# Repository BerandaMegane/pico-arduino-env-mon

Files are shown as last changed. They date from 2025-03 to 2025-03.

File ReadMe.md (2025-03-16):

# pico-arduino-env-mon

秋月電子通商で買える部品だけで作れる環境モニタです。

温度、湿度、気圧、CO2濃度を定期的に取得し、24時間のトレンドグラフとともに表示します。

こちらの環境モニタ (MIT license) を参考に製作しました。
* [shapoco / pico-env-mon](https://github.com/shapoco/pico-env-mon)
  * ReadMe.md を一部流用させていただきました。 
  * グラフ描画処理を参考にさせていただきました。

## 作例

3Dプリンタで作ったケースに収めた例です。

基板の作例は [こちらの img ディレクトリ](img/) を参照してください。

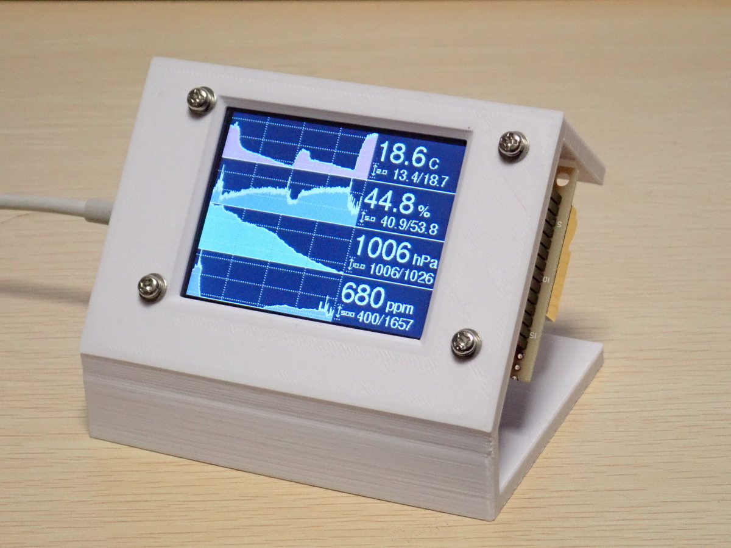
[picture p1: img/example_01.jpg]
作例


## 使用部品

<table>
  <tr>
    <th>項目</th>
    <th>型番・仕様</th>
    <th>購入先 (例)</th>
    <th>備考</th>
  </tr>
  <tr>
    <td rowspan="2">マイコン (どちらか)</td>
    <td>秋月 AE-RP2040</td>
    <td>
      秋月: <a href="https://akizukidenshi.com/catalog/g/g117542/" target="_blank">117542</a>
    </td>
    <td rowspan="2">AE-RP2040で動作確認済み</td>
  </tr>
  <tr>
    <td>Raspberry Pi Pico</td>
    <td>
      秋月: <a href="https://akizukidenshi.com/catalog/g/g116132/" target="_blank">116132</a>
    </td>
  </tr>
  <tr>
    <td>LCD</td>
    <td>MSP2807</td>
    <td>
      秋月: <a href="https://akizukidenshi.com/catalog/g/g116265/" target="_blank">116265</a>
    </td>
    <td>ILI9341 搭載 LCD</td>
  </tr>
  <tr>
    <td>温湿度・気圧センサ</td>
    <td>AE-BME280</td>
    <td>
      秋月: <a href="https://akizukidenshi.com/catalog/g/g109421/" target="blank">109421</a>
    </td>
    <td></td>
  </tr>
  <tr>
    <td>CO2 センサ</td>
    <td>MH-Z19C</td>
    <td>
      秋月: <a href="https://akizukidenshi.com/catalog/g/g116142/" target="blank">116142</a>
    </td>
    <td>*1</td>
  </tr>
  <tr>
    <td>ゼロ点補正スイッチ</td>
    <td>適当なタクトスイッチ</td>
    <td>
      秋月: <a href="https://akizukidenshi.com/catalog/c/cpushsw/" target="blank">検索</a>
      (例: <a href="https://akizukidenshi.com/catalog/g/g103647/" target="blank">103647</a>)
    </td>
    <td></td>
  </tr>
  <tr>
    <td>部品固定用<br>ピンヘッダ</td>
    <td>PH-1x40SG</td>
    <td>
      秋月: <a href="https://akizukidenshi.com/catalog/g/g100167/" target="blank">100167</a>
    </td>
    <td></td>
  </tr>
  <tr>
    <td>部品固定用<br>ピンソケット</td>
    <td>FHU-1x42SG</td>
    <td>
      秋月: <a href="https://akizukidenshi.com/catalog/g/g105779/" target="blank">105779</a>
    </td>
    <td></td>
  </tr>
  <tr>
    <td>ユニバーサル基板</td>
    <td>秋月 Bタイプ 2.54mm</td>
    <td>
      秋月: <a href="https://akizukidenshi.com/catalog/goods/search.aspx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" target="blank">検索</a>
      (例: <a href="https://akizukidenshi.com/catalog/g/g103230/" target="blank">103230</a>)
    </td>
    <td>両面の方が配線しやすい<br>*2</td>
  </tr>
  <tr>
    <td>配線類</td>
    <td>UEW など</td>
    <td>
      秋月: <a href="https://akizukidenshi.com/catalog/c/cwire/" target="blank">検索</a>
      (例: <a href="https://akizukidenshi.com/catalog/g/g109583/" target="blank">109583</a>)
    </td>
    <td></td>
  </tr>
  <tr>
    <td>USB電源</td>
    <td>5V</td>
    <td>
      秋月: <a href="https://akizukidenshi.com/catalog/g/g113658/" target="_blank">113658</a>
    </td>
    <td></td>
  </tr>
  <tr>
    <td>USBケーブル</td>
    <td>Type-C: AE-RP2040, Pi Pico2<br>micro B: Pi Pico</td>
    <td>
      秋月: (例: Type-C <a href="https://akizukidenshi.com/catalog/g/g113563/" target="_blank">113563</a>)
    </td>
    <td>マイコンに適合するもの</td>
  </tr>
</table>

\*1) :warning: MH-Z19C には購入時点でピンヘッダが付いていてそれ自体は 2.54mm ピッチですが、2 つのヘッダの間隔が 2.54mm ピッチのユニバーサル基板に適合しません。  
直接ハンダづけしたい場合は、1.27mm ピッチのユニバーサル基板を使用するか、ピンヘッダを外してスズメッキ線等で配線してください。  
作例ではピンソケットを用いて若干「ハの字」になるように接続しています。

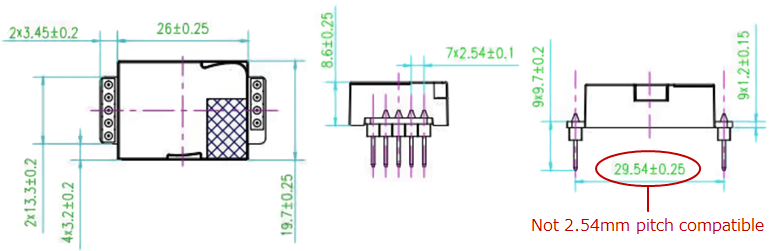
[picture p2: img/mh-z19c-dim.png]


\*2) :warning: ケース用の STL データを使用する場合は適切な大きさにカットする必要があります (後述)。

----

## 接続

|AE-RP2040<br>Raspberry Pi Pico|MSP2807|BME280|MH-Z19C|
|:--|:--|:--|:--|
|`5V`(AE-RP2040)<br>`VBUS`(Pi Pico)|`VCC`||`Vin`|
|`3V3`<br>(AE-RP2040, Pi Pico)||`VDD`||
|`GND`|`GND`|`GND`|`GND`|
|`GPIO0` (uart0 TX)|||`RX`|
|`GPIO1` (uart1 RX)|||`TX`|
|`GPIO16` (spi0 RX)||`SDO`|
|`GPIO17` (spi0 CSn)||`CSB`|
|`GPIO18` (spi0 SCK)|`SCK`|`SCK`|
|`GPIO19` (spi0 TX)|`SDI`|`SDI`|
|`GPIO20`|`DC`||
|`GPIO21`|`RST`||
|`GPIO22`|`CS`||

### AE-RP2040 使用時
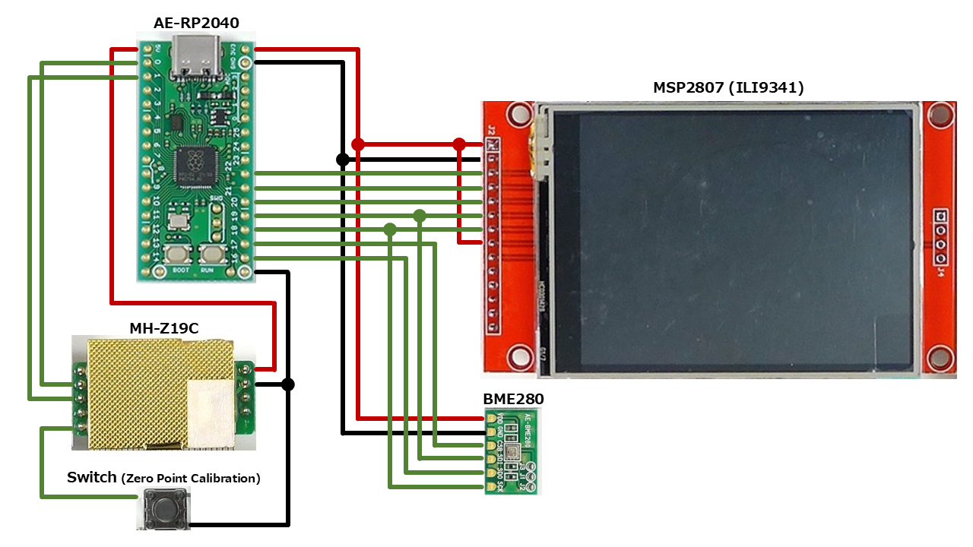
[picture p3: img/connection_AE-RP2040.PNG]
AE-RP2040使用時の接続図


### Raspberry Pi Pico 使用時（未確認）
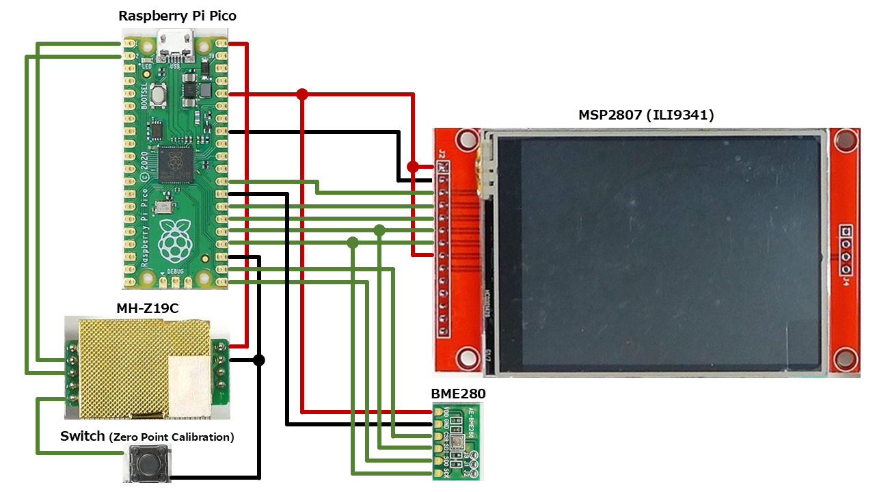
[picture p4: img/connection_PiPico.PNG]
Raspberry Pi Pico使用時の接続図


## 配線・組み立てについて

### 注意事項

:warning: CO2センサー MH-Z19C は内蔵された電球の駆動のために定期的に大きな電流を吸い込みます。これが LCD の動作に悪影響を与えないよう、配線の引き回しやコンデンサの配置に注意する必要があります。

- LCD の表示に問題が生じた場合は:
  - MH-Z19C と LCD それぞれの直近にセラミックコンデンサを実装してみてください。
  - MH-Z19C の直近に電解コンデンサ 47uF を追加してみてください。

### ケースについて

[ケース用の STL のサンプル](case/body.stl) を公開しています。
2.54mm ピッチのユニバーサル基板を 33穴 ✕ 18穴 にカットし、以下のようにレイアウトする前提の形状になっています。

また、STL の元になった [モデルサンプル](case/pico-arduino-env-mon_case.f3d) を公開しています。
Fusion 360 (趣味での利用は無償) で編集することができます。

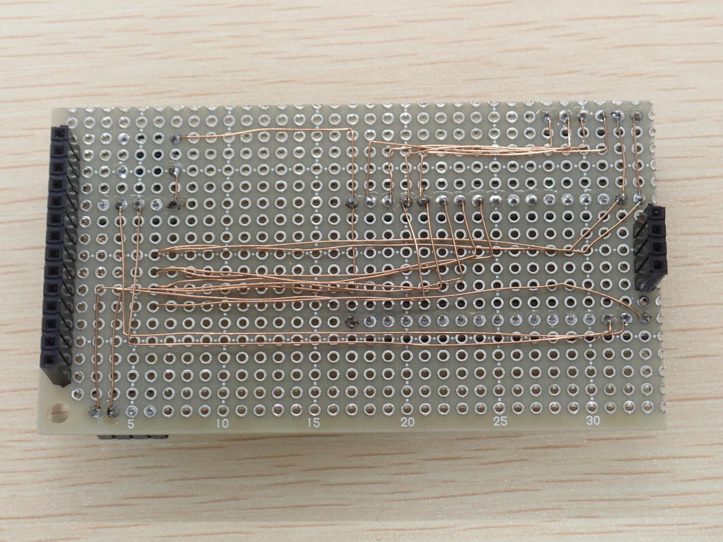
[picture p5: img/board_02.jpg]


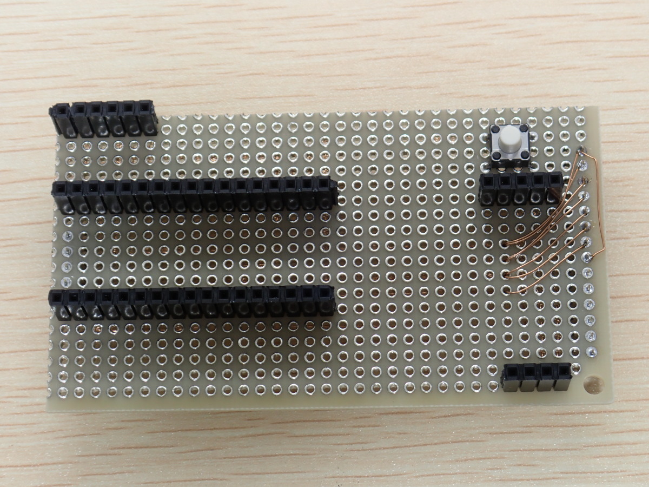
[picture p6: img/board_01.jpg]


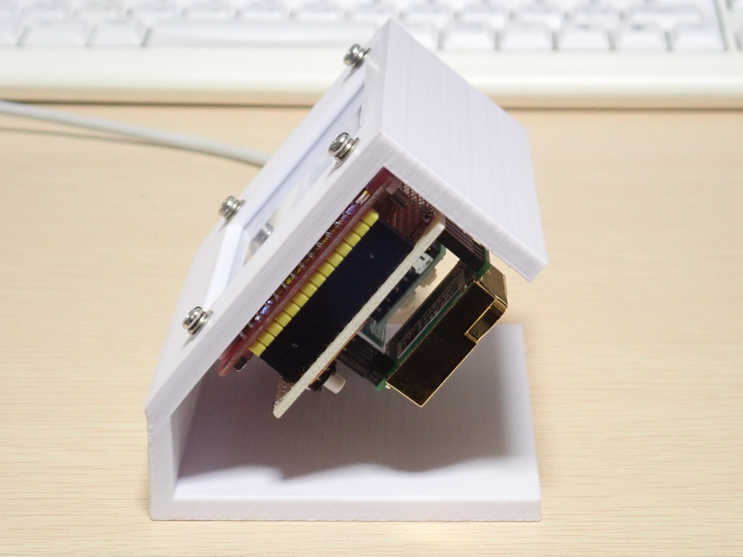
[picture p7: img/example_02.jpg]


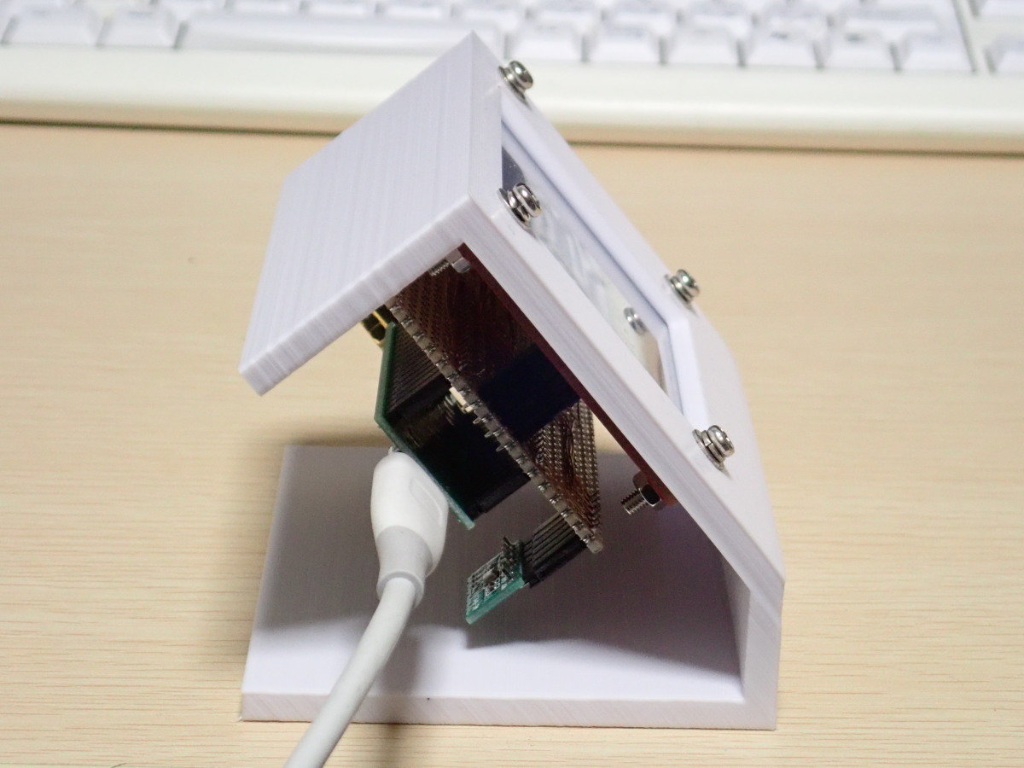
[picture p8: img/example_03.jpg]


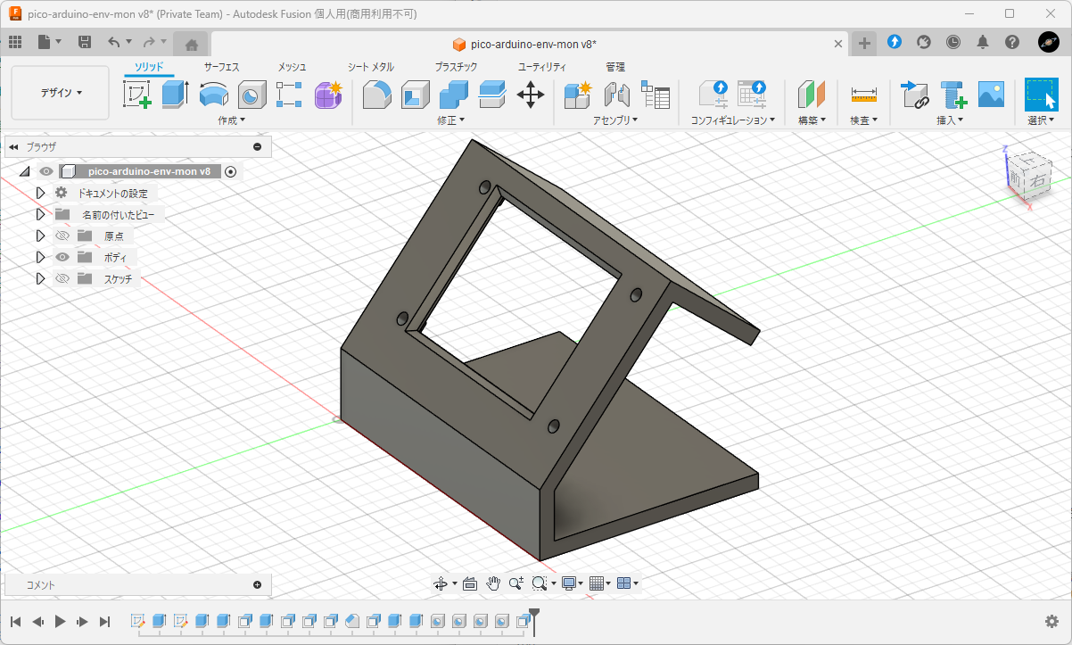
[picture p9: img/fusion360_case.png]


## プログラム

コンパイル済みバイナリをダウンロードしてそのまま書き込むか、またはソースコードからビルドしてください。

### コンパイル済みバイナリ

1. [Releases](https://github.com/BerandaMegane/pico-arduino-env-mon/releases) から、最新バージョンの `pico_arduino_env_mon.uf2` をダウンロードします。
2. マイコンを書き込みモードで PC へ接続します。(USBストレージとして認識されます)  
    書き込みモードへの切り替え方法は使用マイコンによって異なります。
    * Raspberry Pi Pico の場合: `BOOT SEL` ボタンを押しながら USBケーブルを接続します。
    * AE-RP2040 の場合: USBケーブルを接続後、`BOOT` ボタンを押しながら、隣の `RUN` ボタンを押します。
3. `pico-arduino-env-mon.uf2` をマイコンへ書き込みます。

### ソースコードからのビルド

ビルドするには Arduino IDE 2 と Raspberry Pi Pico (RP2040) 開発環境の設定が必要です。  
開発環境の構築方法は次のサイトを参考にしてください。

参考サイト: ロジカラブログ - [ラズパイPico/Pico2/PicoWのArduinoIDE2のインストール方法や使い方紹介](https://logikara.blog/raspi-pico-arduinoide/)

1. 本リポジトリをダウンロードする。

    1. 本ページ上部の `<> Code` をクリック
    2. `Download ZIP` をクリックして任意の場所に展開

2. `pico-arduino-env-mon.ino` を Arduino IDE 2.0 で開く。
3. 必要なライブラリパッケージをインストールする。

    * "Adafruit GFX Library"
    * "Adafruit ILI9341"
    * "Bme280" (by Eduard Malokhvii)

4. マイコンボードの接続設定などを行う。
5. コンパイル＆実行し、ビルドファイルをマイコンへ書き込む。

## 調整

### BME280 の温度

BME280 で取得できる温度の値は湿度と気圧の補正のためのもので、実際の気温より若干高くなります。

> The integrated temperature sensor has been optimized for lowest noise and highest resolution. Its output is used for temperature compensation of the pressure and humidity sensors and can also be used for estimation of the ambient temperature. 

> Temperature measured by the internal temperature sensor. This temperature value depends on the PCB temperature, sensor element self-heating and ambient temperature and is typically above ambient temperature.

実際の気温とどの程度乖離するかはセンサの使用条件によります。ケースに入れたり、BME280 を CO2センサに近接させたりすると乖離が大きくなります。本プロジェクトではこれらを考慮し、デフォルトでは取得した温度から 1.5℃ 減算した値を表示します。

補正値を変更するには、`src/pico-arduino-env-mon.ino` の次の箇所を変更してビルドし直してください。

```c++
const float TEMPERATURE_OFFSET = -2.0;
```

### MH-Z19C のキャリブレーション

MH-Z19C は初期状態では正しい値を示さないケースがあります。

屋外に放置して値が 400ppm 付近まで下がらない場合や、人がいる室内なのに 400ppm 付近に張り付いてしまう場合はキャリブレーションを実施してください。

参考: [Home Assistant: ESP32+MH-Z19CでCO2モニター構築(2) [キャリブレーション編] - Sympapaのスマートホーム日記](https://sympapa.hatenablog.com/entry/2022/06/05/091621)

1. 本機を屋外や誰もいない風通しの良い場所に 20分間放置します。
2. 吐息がかからないように息を止めて、ゼロ点補正 (Zero Point Calibration) スイッチを 7秒間押下します。

なお、本プロジェクトではオートキャリブレーションは無効化されています。

### 時間軸のスケール変更

デフォルトでは 24時間分のグラフが表示されます。

スケールを変更するには、`src/pico-arduino-env-mon.ino` の次の箇所を変更してビルドし直してください。

```c++
const int16_t GRAPH_TIME_RANGE_H = 24;
```

## Lisence

This project is licensed under the MIT License, see the LICENSE.txt file for details

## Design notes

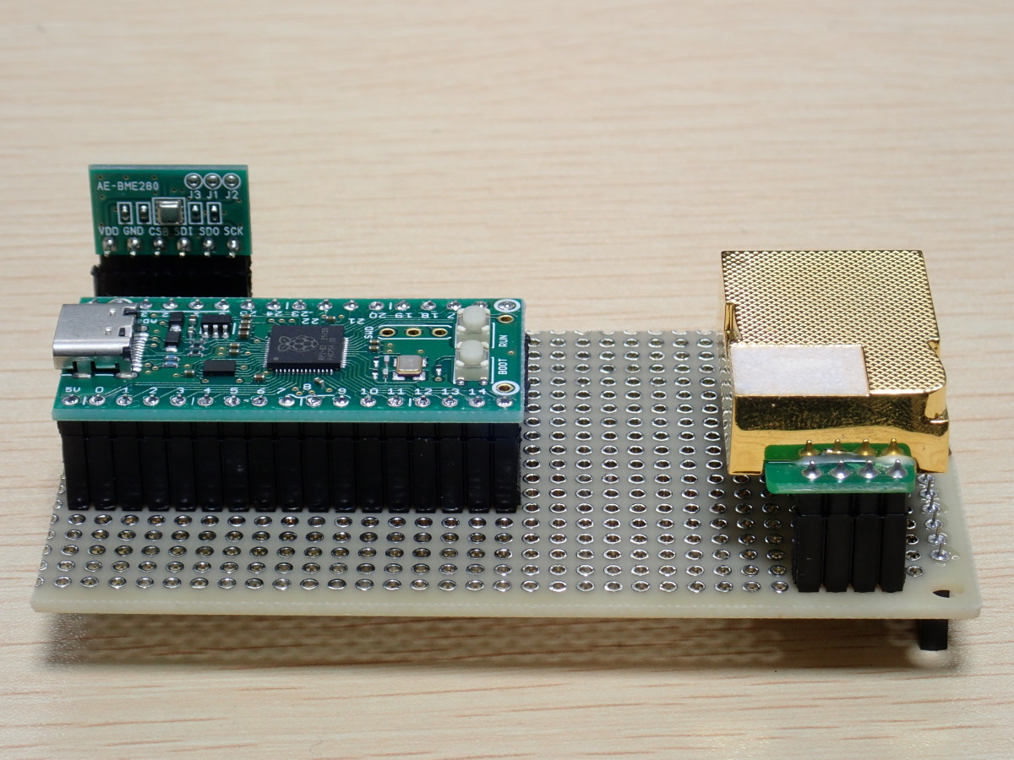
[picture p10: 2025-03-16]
img/board_03.jpg

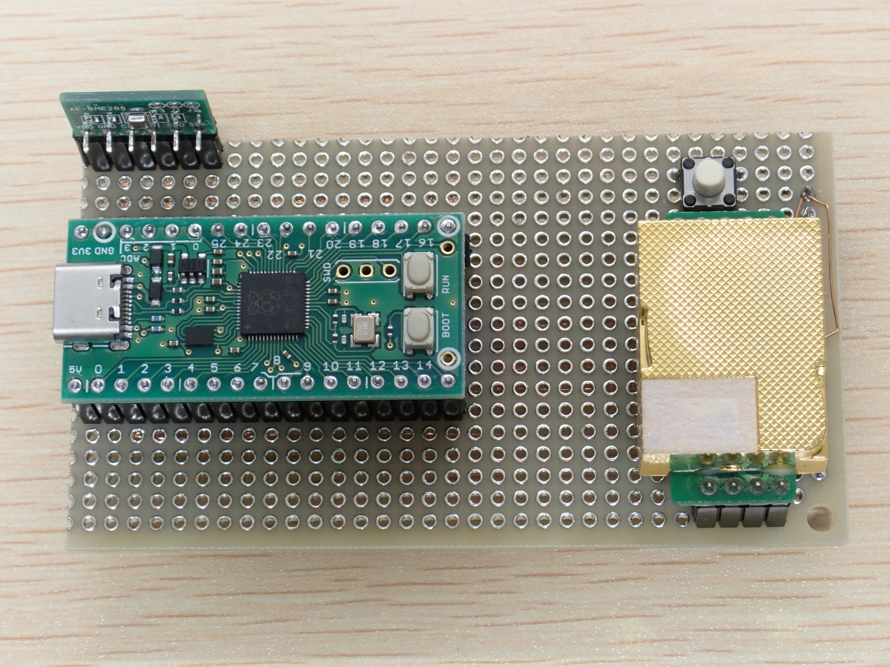
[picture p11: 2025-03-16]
img/board_04.jpg

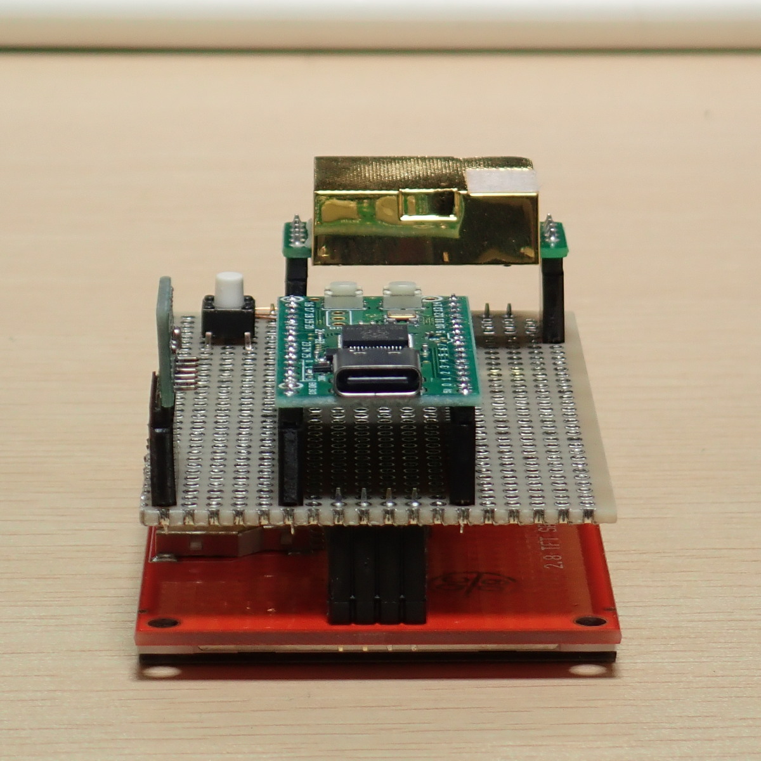
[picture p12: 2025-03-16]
img/board_06.jpg

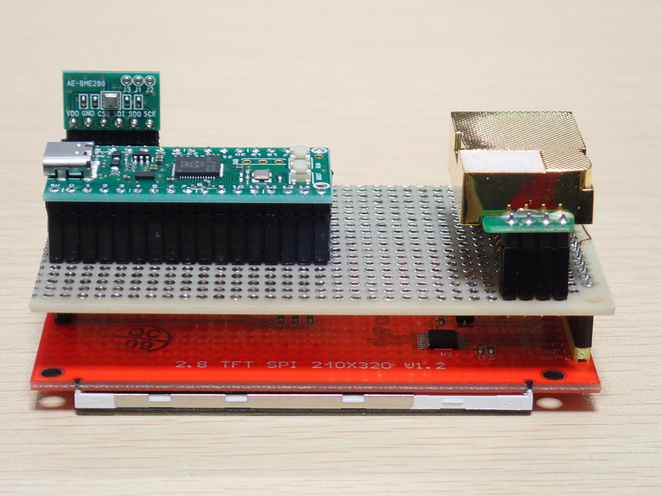
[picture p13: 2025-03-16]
img/board_05.jpg

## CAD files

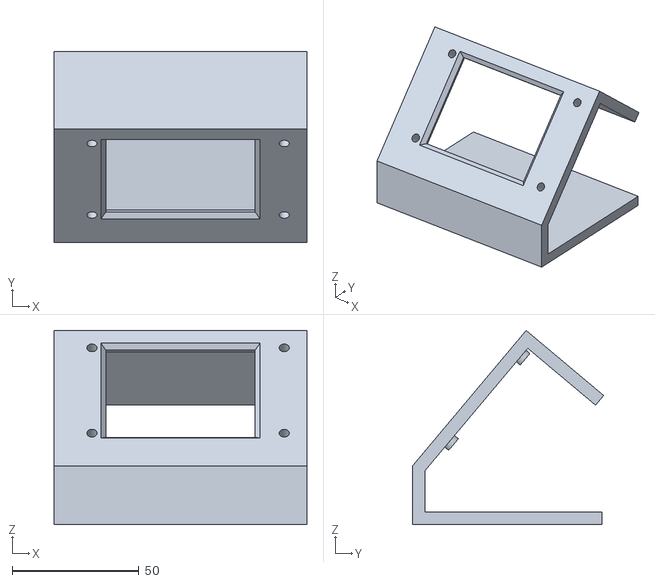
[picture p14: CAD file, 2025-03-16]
case/body.stl
100.0 x 75.6 x 76.7

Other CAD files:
case/pico-arduino-env-mon_case.f3d

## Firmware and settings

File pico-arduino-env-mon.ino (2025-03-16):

/*
Copyright (c) 2022 shapoco
Copyright (c) 2025 BerandaMegane
Released under the MIT license
https://opensource.org/licenses/mit-license.php

shapoco 氏の環境モニタ pico-env-mon を参考に製作しました。
- ReadMe.md を一部流用させていただきました。 
- グラフ描画処理を参考にさせていただきました。
- https://github.com/shapoco/pico-env-mon
*/

// 必要な外部ライブラリ
// https://github.com/adafruit/Adafruit-GFX-Library
#include <Adafruit_GFX.h>  // install "Adafruit GFX Library"
// https://github.com/adafruit/Adafruit_ILI9341
#include <Adafruit_ILI9341.h>  // install "Adafruit ILI9341"
// https://github.com/malokhvii-eduard/arduino-bme280
#include <Bme280.h>  // install "Bme280" (by Eduard Malokhvii)

// フォント
#include <Fonts/FreeSans9pt7b.h>
#include <Fonts/FreeSans18pt7b.h>
#include <Fonts/Org_01.h>

// ピン接続
#define UART_TX    0  // UART TX   (MH-Z19C RX)
#define UART_RX    1  // UART RX   (MH-Z19C TX)
#define SPI_MISO  16  // SPI0 MISO (BME280, ILI9341)
#define BME280_CS 17  // SPI  CS   (BME280)
#define SPI_SCK   18  // SPI0 SCK  (BME280, ILI9341)
#define SPI_MOSI  19  // SPI0 MOSI (BME280, ILI9341)
#define LCD_DC    20  // ILI9341 DC
#define LCD_RST   21  // ILI9341 RST
#define LCD_CS    22  // SPI  CS   (ILITFT_9341)

// 液晶画面
#define LCD_WIDTH    320
#define LCD_HEIGHT   240
#define LCD_ROTATION   1  // 画面の回転 1 or 3
#define LCD_BLACK 0x0000
#define LCD_WHITE 0xFFFF

const int16_t SAMPLING_INTERVAL_MS = 1000;
const int16_t GRAPH_DEPTH = 200;  // グラフの横幅
const int16_t GRAPH_TIME_RANGE_H = 24;  // グラフの全期間の時間
const uint32_t GRAPH_SHIFT_INTERVAL_MS = (uint32_t)GRAPH_TIME_RANGE_H * 3600 * 1000 / GRAPH_DEPTH;

const float TEMPERATURE_OFFSET = -2.0;  // 温度補正値
Bme280FourWire bme280;
Adafruit_ILI9341 lcd = Adafruit_ILI9341(&SPI, LCD_DC, LCD_CS, LCD_RST);
GFXcanvas16 canvas(LCD_WIDTH, LCD_HEIGHT);

void drawInvertDottedVLine(int16_t x, int16_t y, int16_t h, int16_t invert_dot, int16_t not_invert_dot) {
  const int16_t length = invert_dot + not_invert_dot;
  int16_t i = 0;
  for (int16_t px_y = y; px_y < (y + h); px_y++) {
    if ((i % length) < invert_dot) {
      canvas.drawPixel(x, px_y, 0xFFFF - canvas.getPixel(x, px_y));
    }
    i++;
  }
}

void drawInvertDottedHLine(int16_t x, int16_t y, int16_t h, int16_t invert_dot, int16_t not_invert_dot) {
  const int16_t length = invert_dot + not_invert_dot;
  int16_t i = 0;
  for (int16_t px_x = x; px_x < (x + h); px_x++) {
    if ((i % length) < invert_dot) {
      canvas.drawPixel(px_x, y, 0xFFFF - canvas.getPixel(px_x, y));
    }
    i++;
  }
}

void drawDottedVLine(int16_t x, int16_t y, int16_t h, uint16_t color, int16_t invert_dot, int16_t not_invert_dot) {
  const int16_t length = invert_dot + not_invert_dot;
  int16_t i = 0;
  for (int16_t px_y = y; px_y < (y + h); px_y++) {
    if ((i % length) < invert_dot) {
      canvas.drawPixel(x, px_y, color);
    }
    i++;
  }
}

void drawDottedHLine(int16_t x, int16_t y, int16_t h, uint16_t color, int16_t invert_dot, int16_t not_invert_dot) {
  const int16_t length = invert_dot + not_invert_dot;
  int16_t i = 0;
  for (int16_t px_x = x; px_x < (x + h); px_x++) {
    if ((i % length) < invert_dot) {
      canvas.drawPixel(px_x, y, color);
    }
    i++;
  }
}

uint16_t get16bitColor(uint8_t r, uint8_t g, uint8_t b) {
  // 0b RRRR RGGG GGGB BBBB
  return r << 11 | g << 5 | b;
} 

uint16_t get16bitColor(float r, float g, float b) {
  uint8_t temp_r = r * 0b11111;
  uint8_t temp_g = g * 0b111111;
  uint8_t temp_b = b * 0b11111;
  return get16bitColor(temp_r, temp_g, temp_b);
}

class Graph {
public:
  // サンプル数
  static const int DEPTH = GRAPH_DEPTH;
  // グラフのサイズ
  static const int WIDTH = DEPTH;
  static const int HEIGHT = 60;
  // 垂直線の間隔
  static const int VERTICAL_LINE_STEP = WIDTH / 4;

  // グラフの位置
  const int left, top;
  // 最小の縦方向範囲
  const float min_range;
  // 最小値・最大値の履歴
  float min_log[DEPTH];
  float max_log[DEPTH];
  // 現在のデータ数
  int num_data = 0;
  // グラフ全体の最小値・最大値
  float total_min = 0;
  float total_max = 0;
  // 水平線の間隔
  float horizontal_line_step = 1;

  const uint16_t plot_color;
  const uint16_t fill_color;

  // コンストラクタ
  Graph(int x, int y, float min_range, uint16_t plot_color, uint16_t fill_color) : 
    left(x), top(y), min_range(min_range), plot_color(plot_color), fill_color(fill_color) { }

  // データを追加する関数
  void push(float value, bool shift) {
    if (num_data == 0) {
      // 最初のデータを追加
      num_data = 1;
      min_log[0] = max_log[0] = value;
    } else if (shift) {
      // 新しいデータを追加し、過去のデータを1つ後ろにシフト
      for (int i = DEPTH - 1; i >= 1; i--) {
        min_log[i] = min_log[i-1];
        max_log[i] = max_log[i-1];
      }
      min_log[0] = max_log[0] = value;
      if (num_data < DEPTH) {
        num_data++;
      }
    } else {
      // 最新のデータと比較し、最小・最大値を更新
      if (min_log[0] > value) min_log[0] = value;
      if (max_log[0] < value) max_log[0] = value;
    }
    
    // グラフ全体の最小・最大値を更新
    if (num_data == 0) {
      total_min = 0;
      total_max = 0;
    } else {
      total_min = min_log[0];
      total_max = max_log[0];
      for (int i = 1; i < num_data; i++) {
        if (min_log[i] < total_min) total_min = min_log[i];
        if (max_log[i] > total_max) total_max = max_log[i];
      }
    }
  }

  // グラフを描画する関数
  void render() {
    if (num_data <= 0) return;

    canvas.fillRect(left, top, WIDTH, HEIGHT, LCD_BLACK);

    float total_center = (total_min + total_max) / 2;  // 中間データ
    float y_range = total_max - total_min;  // 表示データの範囲
    if (y_range < min_range) y_range = min_range;
    float y_zoom = HEIGHT / y_range;
    int y_offset = top + HEIGHT / 2 + total_center * y_zoom;  // グラフ下端

    // Serial.printf("%f %f %f %d\n", total_center, y_range, y_zoom, y_offset);

    // グラフ右端から左端に向けて走査
    int x_plot = left + WIDTH - 1;
    for (int i = 0; i < num_data; i++) {
      // shift するまでに push されたデータの最大値から最小値まで縦線を引く
      int y_top    = y_offset - max_log[i] * y_zoom;
      int y_bottom = y_offset - min_log[i] * y_zoom;
      canvas.drawFastVLine(x_plot, y_top, y_bottom - y_top + 1, plot_color);
      // Serial.printf("x:%d y:%d h:%d top:%d bottom:%d\n", x_plot, y_top, y_bottom - y_top, y_top, y_bottom);
      canvas.drawFastVLine(x_plot, y_bottom+1, top + HEIGHT - (y_bottom+1) , fill_color);
      // canvas.drawFastVLine(x_plot, y_bottom+1, 2 , 0xF800);
      x_plot--;
    }

    // スケール垂直線を描画
    for (int x = left + WIDTH - 1; x > left; x -= VERTICAL_LINE_STEP) {
      drawInvertDottedVLine(x, top, HEIGHT, 1, 2);
    }

    // Y軸のスケール計算
    float level_top = (y_offset - top) / y_zoom;
    float level_bottom = (y_offset - (top + HEIGHT)) / y_zoom;
    float y_scale = level_top - level_bottom;

    // 水平線の間隔を決定
    if      (y_scale > 1000) horizontal_line_step = 500;
    else if (y_scale >  500) horizontal_line_step = 200;
    else if (y_scale >  200) horizontal_line_step = 100;
    else if (y_scale >  100) horizontal_line_step =  50;
    else if (y_scale >   50) horizontal_line_step =  20;
    else if (y_scale >   20) horizontal_line_step =  10;
    else if (y_scale >   10) horizontal_line_step =   5;
    else if (y_scale >    5) horizontal_line_step =   2;
    else if (y_scale >    2) horizontal_line_step =   1;
    else if (y_scale >    1) horizontal_line_step =   0.5f;
    else                     horizontal_line_step =   0.2f;
    
    // 水平線を描画
    float level = horizontal_line_step * ceilf(level_bottom / horizontal_line_step);
    while (level < level_top) {
      int y_line = y_offset - level * y_zoom;
      drawDottedHLine(left, y_line, WIDTH, LCD_WHITE, 1, 2);
      level += horizontal_line_step;
    }

  }

  // 現在の測定値表示
  void drawValue(float value, char * value_format, char * unit) {
    canvas.setTextColor(LCD_WHITE);
    const GFXfont * value_font = &FreeSans18pt7b;
    const GFXfont * unit_font = &FreeSans9pt7b;
    
    const int16_t cursor_x = left + 200;
    const int16_t cursor_y = top + 62;
    const int16_t offset_value_h = 3;
    const int16_t offset_value_v = 30;

    canvas.setCursor(cursor_x+offset_value_h, cursor_y-offset_value_v);
    canvas.setFont(value_font);
    canvas.printf(value_format, value);
    canvas.setFont(unit_font);
    canvas.print(unit);
  }
  
  // スケール、最小値/最大値
  void drawLegend(char * minmax_format, char * scale_format) {
    canvas.setTextColor(LCD_WHITE);
    const GFXfont * minmax_font = &FreeSans9pt7b;
    const GFXfont * scale_font = &Org_01;

    const int16_t cursor_x = left + 200;
    const int16_t cursor_y = top + 60;

    const int16_t offset_minmax_h = 30;
    const int16_t offset_minmax_v = 8;
    canvas.setCursor(cursor_x+offset_minmax_h, cursor_y-offset_minmax_v);
    canvas.setFont(minmax_font);
    canvas.printf(minmax_format, total_min, total_max);

    // スケール
    canvas.setCursor(cursor_x+10, cursor_y-12);
    canvas.setFont(scale_font);
    canvas.printf(scale_format, horizontal_line_step);

    // スケール図形
    const int16_t scale_arrow_size = 13;
    const int16_t scale_arrow_y1 = cursor_y-23+2;
    const int16_t scale_arrow_y2 = scale_arrow_y1 + scale_arrow_size;
    const int16_t scale_arrow_x = cursor_x+6;
    drawInvertDottedHLine(cursor_x+3, cursor_y-5, 8, 1, 2);
    drawInvertDottedHLine(cursor_x+3, cursor_y-23, 8, 1, 2);
    canvas.drawFastVLine(scale_arrow_x, scale_arrow_y1, scale_arrow_size, LCD_WHITE);
    canvas.drawLine(scale_arrow_x, scale_arrow_y1 , scale_arrow_x-2, scale_arrow_y1+2, LCD_WHITE);  // 左下へ
    canvas.drawLine(scale_arrow_x, scale_arrow_y1 , scale_arrow_x+2, scale_arrow_y1+2, LCD_WHITE);  // 右下へ
    canvas.drawLine(scale_arrow_x, scale_arrow_y2 , scale_arrow_x-2, scale_arrow_y2-2, LCD_WHITE);  // 左上へ
    canvas.drawLine(scale_arrow_x, scale_arrow_y2 , scale_arrow_x+2, scale_arrow_y2-2, LCD_WHITE);  // 右上へ
  }
};

// MH-Z19C
uint8_t ReadCO2[9] = {0xFF, 0x01, 0x86, 0x00, 0x00, 0x00, 0x00, 0x00, 0x79};
uint8_t SelfCalOn[9]  = {0xFF, 0x01, 0x79, 0xA0, 0x00, 0x00, 0x00, 0x00, 0xE6};
uint8_t SelfCalOff[9] = {0xFF, 0x01, 0x79, 0x00, 0x00, 0x00, 0x00, 0x00, 0x86};

void mhz19c_init() {
  uint8_t resp[9];

  pinMode(UART_RX, INPUT);
  pinMode(UART_TX, OUTPUT);

  Serial1.begin(9600);
  Serial1.write(SelfCalOff, sizeof SelfCalOff);
  delay(100);

  Serial1.readBytes((char *)resp, sizeof resp);
  delay(100);
}

bool mhz19c_measure(int *result) {
  uint8_t resp[9];

  Serial1.write(ReadCO2,sizeof ReadCO2);
  Serial1.readBytes((char *)resp, sizeof resp);
  
  if (resp[0] == 0xff && resp[1] == 0x86) {
      *result = resp[2] * 256 + resp[3];
      return true;
  }
  else {
      *result = -1;
      return false;
  }
}

void setup() {
  // SPI 初期設定
  SPI.setTX(SPI_MOSI);
  SPI.setRX(SPI_MISO);
  SPI.setSCK(SPI_SCK);
  SPI.begin();

  // 液晶画面初期設定
  lcd.begin();
  lcd.setRotation(LCD_ROTATION);

  // センサ
  bme280.begin(BME280_CS, &SPI);
  bme280.setSettings(Bme280Settings::indoor());
  mhz19c_init();

  Serial.begin(9600);
  Serial.printf("Hello RP2040-env-mon!\n");
}

void loop() {
  // グラフのシフトタイミング
  static unsigned long next_lcd_shift_ms = GRAPH_SHIFT_INTERVAL_MS;
  bool shift = false;
  if (millis() >= next_lcd_shift_ms) {
    // millis() + GRAPH_SHIFT_INTERVAL_MS がオーバーフローしたとき、
    // 2連続で shift してしまうが、頻度は少ないので無視する
    next_lcd_shift_ms = millis() + GRAPH_SHIFT_INTERVAL_MS;
    shift = true;
    Serial.println("lcd shift!");
  }

  // グラフ
  canvas.fillScreen(LCD_BLACK);
  static Graph graph_t(0,   0,  1.0f, LCD_WHITE, get16bitColor(1.0f, 0.5f, 0.5f));  // temperature: 気温
  static Graph graph_h(0,  60, 10.0f, LCD_WHITE, get16bitColor(0.5f, 0.5f, 1.0f));  // humidity: 湿度
  static Graph graph_p(0, 120,  1.0f, LCD_WHITE, get16bitColor(0.5f, 1.0f, 0.5f));  // pressure: 気圧
  static Graph graph_c(0, 180, 10.0f, LCD_WHITE, get16bitColor(0.5f, 0.5f, 0.5f));  // CO2
  
  // BME280
  static float pre_temperature = 20.0;
  float t = bme280.getTemperature() + TEMPERATURE_OFFSET;
  float temperature;
  if (isfinite(t)) {
    temperature = t;
    pre_temperature = t;
  } else {
    // 無限大取得時の対応（稀に検出）
    temperature = pre_temperature;
  }
  float pressure = bme280.getPressure();
  float humidity = bme280.getHumidity();
  
  // MH-Z19C
  int co2 = 0;
  mhz19c_measure(&co2);
  
  // デバッグ用
  Serial.printf("%.1f ℃, %.1f %%, %.f hPa, %d ppm\n", temperature, humidity, pressure/100, co2);
  
  // グラフ描画
  graph_t.push(temperature, shift);
  graph_h.push(humidity, shift);
  graph_p.push(pressure/100, shift);
  graph_c.push(co2, shift);
  graph_t.render();
  graph_h.render();
  graph_p.render();
  graph_c.render();

  // 水平線
  canvas.drawFastHLine(0,  60-1, LCD_WIDTH, LCD_WHITE);
  canvas.drawFastHLine(0, 120-1, LCD_WIDTH, LCD_WHITE);
  canvas.drawFastHLine(0, 180-1, LCD_WIDTH, LCD_WHITE);

  // 値 + 単位
  graph_t.drawValue(temperature, "%.1f", " C");
  graph_h.drawValue(humidity, "%.1f", " %");
  graph_p.drawValue(pressure/100, "%.f", " hPa");
  graph_c.drawValue(co2, "%.f", " ppm");

  // 最小値/最大値 + 1div
  graph_t.drawLegend("%.1f/%.1f", "%.1f");
  graph_h.drawLegend("%.1f/%.1f", "%.1f");
  graph_p.drawLegend("%.f/%.f", "%.1f");
  graph_c.drawLegend("%.f/%.f", "%.f");

  // TFTに描画
  lcd.drawRGBBitmap(0, 0, canvas.getBuffer(), LCD_WIDTH, LCD_HEIGHT);

  // デバッグ用
  // Serial.printf("millis(): %lu\n", millis());

  delay(SAMPLING_INTERVAL_MS);
}

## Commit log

2025-03-16 名前修正
    [body.stl]
2025-03-16 ケース追加
    [pico-arduino-env-mon_case.f3d]
2025-03-16 バイナリ提供の文言修正
